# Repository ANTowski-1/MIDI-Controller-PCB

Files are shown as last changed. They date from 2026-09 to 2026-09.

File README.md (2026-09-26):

# MIDI-Controller-PCB

REV: 1 — Known problems:
    Encoder A/B pins are connected to MCP23017, which makes them unusable, so mannual connection to free ESP GPIO pins is needed,
    Leds near Mute Buttons, aren't working corrctly, as they light up very dim becouse of capabilites of MCP23017 (digital representation is working on screen),
    Some of silkscreen markings are not correct (Pin description for display header)
    
Before building using 1st revision think it through, but if you are intrested in 2nd revision, it will propably be done in the end of the year, based on intrest, so create an issue or write to me directly to let me know about your intrest!

This Repo contains KiCad projects of MIDI-Controller PCB.
Whole documentation can be found in separate repo: ANTowski-1/MIDI-Controller.
(As of end of September 2026, documentations is not made as for code still being developed)

This is an Hobbyst-made project, that isn't connected with MIDI Association in any way, apart from utilising the MIDI 2.0 standard.

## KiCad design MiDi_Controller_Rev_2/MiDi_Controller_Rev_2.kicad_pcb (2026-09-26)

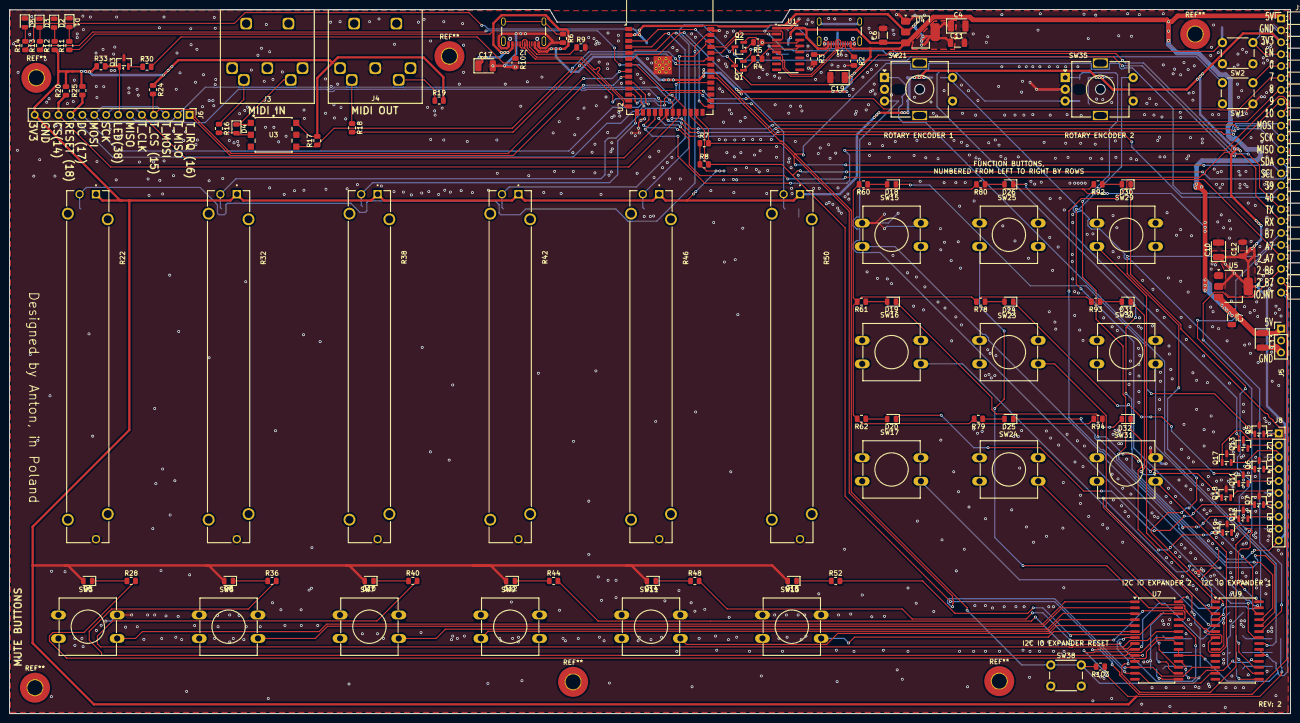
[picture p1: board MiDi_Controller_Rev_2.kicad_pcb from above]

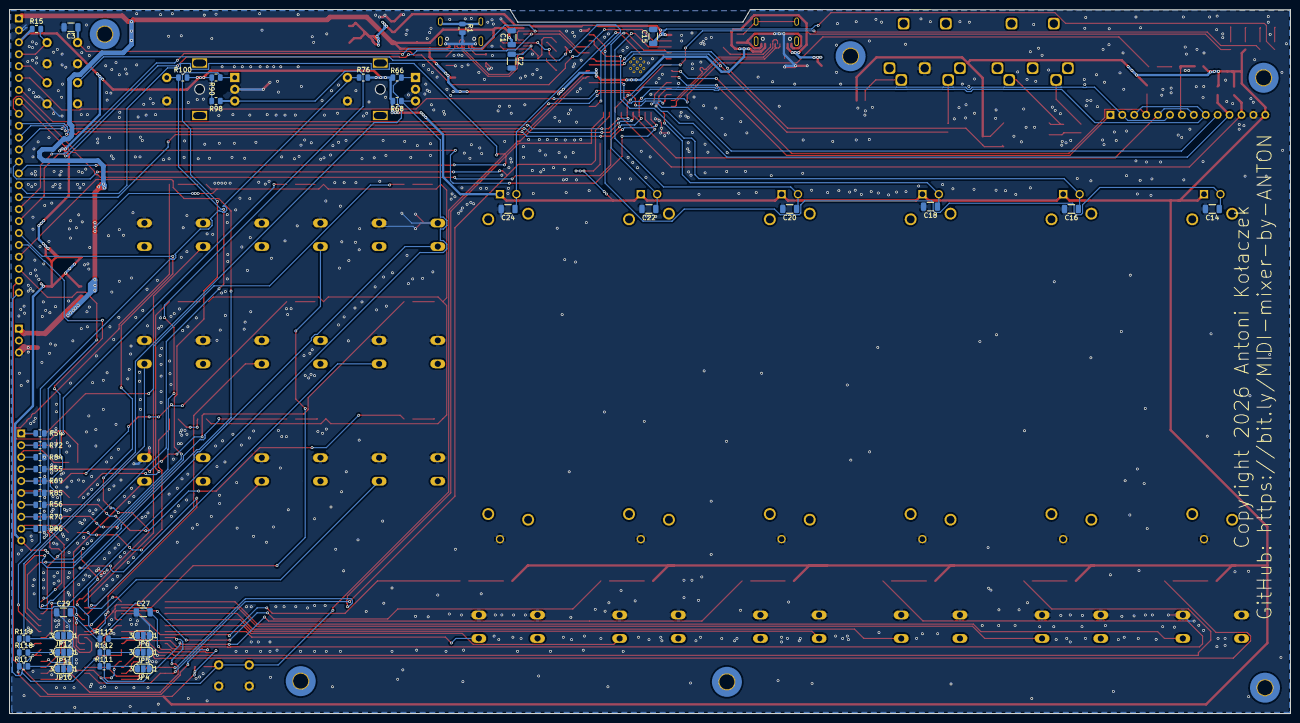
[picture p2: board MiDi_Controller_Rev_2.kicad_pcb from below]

Board: 2 copper layers, 272.9 x 150.0 mm, 161 parts (41 on the bottom side), 138 nets.

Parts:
C1, C2, C14, C15, C16, C18, C20, C22, C24: 100nF; C_1206_3216Metric
C3: 1u; C_1206_3216Metric
C4, C10: C_Polarized; CP_EIA-3528-21_Kemet-B
C6, C7, C11, C12, C27, C29: 100n; C_1206_3216Metric
C13, C17, C19: 10µ C_Polarized; CP_EIA-3528-21_Kemet-B
D1, D18, D19, D20, D24, D25, D26, D30, D31, D32: BLUE; LED_0805_2012Metric
D2, D5: GREEN; LED_0805_2012Metric
D3, D6, D8, D10, D12, D14, D16: RED; LED_0805_2012Metric
D4: D; D_0805_2012Metric
J1, J2: USB_C_Receptacle_USB2.0_16P; USB_C_Receptacle_GCT_USB4105-xx-A_16P_TopMnt_Horizontal
J3, J4: DIN-5; DIN-5-lumberg-0105
J5: Conn_01x03_Pin; PinHeader_1x03_P2.54mm_Vertical
J6: Display; PinHeader_1x14_P2.54mm_Vertical
J8: KEYPAD_LEDS; PinSocket_1x10_P2.54mm_Vertical
J10: Conn_01x24_Pin; PinHeader_1x24_P2.54mm_Horizontal
JP4, JP5, JP6, JP10, JP11, JP12: Jumper_3_Bridged12; SolderJumper-3_P1.3mm_Open_RoundedPad1.0x1.5mm_NumberLabels
Q1, Q2: BC817; SOT-23
Q3, Q5, Q6, Q7, Q11, Q12, Q13, Q17, Q18, Q19: NMOS; SOT-23
R1, R6: 1M; R_0805_2012Metric
R2, R3, R9, R10: 5k1; R_0805_2012Metric
R4, R5, R20, R24, R25, R30, R33, R54, R55, R56, R69, R70, R72, R84, R85, R86: 10K; R_0805_2012Metric
R7, R8: 4k7; R_0805_2012Metric
R11, R60, R61, R62, R78, R79, R80, R92, R93, R94: 110R; R_0805_2012Metric
R12, R14: 47R; R_0805_2012Metric
R13, R28, R36, R40, R44, R48, R52: 82R; R_0805_2012Metric
R15: 5.1K; R_0805_2012Metric
R16, R18: 220R; R_0805_2012Metric
R17: 680R; R_0805_2012Metric
R19: 33R; R_0805_2012Metric
R22, R32, R38, R42, R46, R50: PTA6043-2015DPB103; TRIM_PTA6043-2015DPB103
R66, R68, R76, R90, R98, R100, R103, R111, R112, R113, R117, R118, R119: 10k; R_0805_2012Metric
SW1, SW2: TS-1088-AR02016; SW_PUSH_6mm_H5mm
SW3, SW5, SW7, SW9, SW11, SW13, SW15, SW16, SW17, SW23, SW24, SW25, SW29, SW30, SW31: SW_Push; SW_PUSH-12mm
SW21, SW35: RotaryEncoder_Switch; RotaryEncoder_Alps_EC11E-Switch_Vertical_H20mm_MountingHoles
SW38: SW_Push; SW_PUSH_6mm_H4.3mm
U1: CH340C; SOIC-16_3.9x9.9mm_P1.27mm
U2: ESP32-S3-WROOM-1
U3: H11L1; H11L1STA_EVE
U4, U5: AMS1117-3.3; SOT-223-3_TabPin2
U7, U9: MCP23017x-x-SO; SOIC-28W_7.5x17.9mm_P1.27mm

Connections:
2_GPA0: R28.2, U7.21 (GPA0)
2_GPA1: R36.2, U7.22 (GPA1)
2_GPA2: R40.2, U7.23 (GPA2)
2_GPA3: R44.2, U7.24 (GPA3)
2_GPA4: R48.2, U7.25 (GPA4)
2_GPA5: R52.2, U7.26 (GPA5)
2_GPA6: SW25.2, U7.27 (GPA6)
2_GPA7: J10.21, U7.28 (GPA7)
2_GPB0: SW3.2, U7.1 (GPB0)
2_GPB1: SW5.2, U7.2 (GPB1)
2_GPB2: SW7.2, U7.3 (GPB2)
2_GPB3: SW9.2, U7.4 (GPB3)
2_GPB4: SW11.2, U7.5 (GPB4)
2_GPB5: SW13.2, U7.6 (GPB5)
2_GPB6: J10.22, U7.7 (GPB6)
2_GPB7: J10.23, U7.8 (GPB7)
+3V3: C10.1, C12.1, C27.2, C29.2, D6.2 (A), D8.2 (A), D10.2 (A), D12.2 (A), D14.2 (A), D16.2 (A), J6.14, J8.10, J10.3, R7.1, R8.1, R12.1, R15.1, R17.2, R19.2, R20.2, R22.1, R24.1, R25.2, R32.1, R33.1, R38.1, R42.1, R46.1, R50.1, R66.2, R68.2, R76.2, R90.2, R98.2, R100.2, R103.1, R111.1, R112.1, R113.1, R117.1, R118.1, R119.1, U3.6, U5.2 (VO), U7.9 (V_{DD}), U9.9 (V_{DD})
+5V: C1.1, C6.1, C7.1, C13.1, C17.1, C19.1, J1.A4 (VBUS), J1.A9 (VBUS), J1.B4 (VBUS), J1.B9 (VBUS), J2.A4 (VBUS), J2.A9 (VBUS), J2.B4 (VBUS), J2.B9 (VBUS), J5.1, J10.1, R11.1, R60.2, R61.2, R62.2, R78.2, R79.2, R80.2, R92.2, R93.2, R94.2, U1.16 (VCC), U4.3 (VI), U5.3 (VI)
A0: JP10.2 (C), U9.15 (A0)
A0_2: JP4.2 (C), U7.15 (A0)
A1: JP11.2 (C), U9.16 (A1)
A1_2: JP5.2 (C), U7.16 (A1)
A2: JP12.2 (C), U9.17 (A2)
A2_2: JP6.2 (C), U7.17 (A2)
D+: J2.A6 (D+), J2.B6 (D+), U2.14 (USB_D+)
D-: J2.A7 (D-), J2.B7 (D-), U2.13 (USB_D-)
DS+: J1.A6 (D+), J1.B6 (D+), U1.5 (UD+)
DS-: J1.A7 (D-), J1.B7 (D-), U1.6 (UD-)
EN: C3.1, J10.4, Q1.3 (C), R15.2, SW2.2, U2.3 (EN)
GND: C1.2, C2.2, C3.2, C4.2, C6.2, C7.2, C10.2, C11.2, C12.2, C13.2, C14.2, C15.2, C16.2, C17.2, C18.2, C19.2, C20.2, C22.2, C24.2, C27.1, C29.1, D1.1 (K), D2.1 (K), D3.1 (K), D5.1 (K), J1.A1 (GND), J1.A12 (GND), J1.B1 (GND), J1.B12 (GND), J2.A1 (GND), J2.A12 (GND), J2.B1 (GND), J2.B12 (GND), J4.2, J5.3, J6.13, J10.2, JP4.1 (A), JP5.1 (A), JP6.1 (A), JP10.1 (A), JP11.1 (A), JP12.1 (A), Q3.3 (S), Q5.3 (S), Q6.3 (S), Q7.3 (S), Q11.3 (S), Q12.3 (S), Q13.3 (S), Q17.3 (S), Q18.3 (S), Q19.3 (S), R1.2, R2.2, R3.2, R6.2, R9.2, R10.2, R22.3, R32.3, R38.3, R42.3, R46.3, R50.3, R54.1, R55.1, R56.1, R69.1, R70.1, R72.1, R84.1, R85.1, R86.1, SW1.1, SW2.1, SW3.1, SW5.1, SW7.1, SW9.1, SW11.1, SW13.1, SW15.1, SW16.1, SW17.1, SW21.C, SW21.S1, SW23.1, SW24.1, SW25.1, SW29.1, SW30.1, SW31.1, SW35.C, SW35.S1, SW38.2, U1.1 (GND), U2.1 (GND), U2.40 (GND), U2.41 (GND), U3.5, U4.1 (GND), U5.1 (GND), U7.10 (V_{SS}), U9.10 (V_{SS})
GPA0: R66.1, SW21.A, U9.21 (GPA0)
GPA1: R68.1, SW21.B, U9.22 (GPA1)
GPA2: R76.1, SW21.S2, U9.23 (GPA2)
GPA3: R90.1, SW35.A, U9.24 (GPA3)
GPA4: R98.1, SW35.B, U9.25 (GPA4)
GPA5: R100.1, SW35.S2, U9.26 (GPA5)
GPA6: SW15.2, U9.27 (GPA6)
GPA7: J10.20, U9.28 (GPA7)
GPB0: SW29.2, U9.1 (GPB0)
GPB1: SW16.2, U9.2 (GPB1)
GPB2: SW23.2, U9.3 (GPB2)
GPB3: SW30.2, U9.4 (GPB3)
GPB4: SW17.2, U9.5 (GPB4)
GPB5: SW24.2, U9.6 (GPB5)
GPB6: SW31.2, U9.7 (GPB6)
GPB7: J10.19, U9.8 (GPB7)
GPIO0: J10.5, Q2.3 (C), SW1.2, U2.27 (IO0)
GPIO1: C14.1, R22.2, U2.39 (IO1)
GPIO2: C16.1, R32.2, U2.38 (IO2)
GPIO3: C18.1, R38.2, U2.15 (IO3)
GPIO4: C20.1, R42.2, U2.4 (IO4)
GPIO5: C22.1, R46.2, U2.5 (IO5)
GPIO6: C24.1, R50.2, U2.6 (IO6)
GPIO7: J10.6, U2.7 (IO7)
GPIO8: J10.7, U2.12 (IO8)
GPIO9: J10.8, U2.17 (IO9)
GPIO10: J10.9, U2.18 (IO10)
GPIO11: J6.3, J6.9, J10.10, U2.19 (IO11)
GPIO12: J6.5, J6.8, J10.11, U2.20 (IO12)
GPIO13: J6.2, J6.6, J10.12, U2.21 (IO13)
GPIO14: J6.12, R20.1, U2.22 (IO14)
GPIO15: J6.4, R24.2, U2.8 (IO15)
GPIO16: J6.1, U2.9 (IO16)
GPIO17: J6.10, U2.10 (IO17)
GPIO18: J6.11, R25.1, U2.11 (IO18)
GPIO21: R13.1, U2.23 (IO21)
GPIO38: R30.2, U2.31 (IO38)
GPIO39: J10.15, R103.2, SW38.1, U2.32 (IO39), U7.18 (~RESET), U9.18 (~RESET)
GPIO40: J10.16, U2.33 (IO40)
GPIO41: R18.2, U2.34 (IO41)
GPIO42: R17.1, U2.35 (IO42), U3.4
INTA: J10.24, U7.19 (INTB), U7.20 (INTA), U9.19 (INTB), U9.20 (INTA)
unnamed: D1.2 (A), R11.2
unnamed: D2.2 (A), R12.2
unnamed: D3.2 (A), R13.2
unnamed: D4.2 (A), R16.2, U3.2
unnamed: D4.1 (K), J3.5, U3.1
unnamed: D5.2 (A), R14.2
unnamed: D6.1 (K), R28.1
unnamed: D8.1 (K), R36.1
unnamed: D10.1 (K), R40.1
unnamed: D12.1 (K), R44.1
unnamed: D14.1 (K), R48.1
unnamed: D16.1 (K), R52.1
unnamed: D18.2 (A), R60.1
unnamed: D18.1 (K), Q5.1 (D)
unnamed: D19.2 (A), R61.1
unnamed: D19.1 (K), Q6.1 (D)
unnamed: D20.2 (A), R62.1
unnamed: D20.1 (K), Q7.1 (D)
unnamed: D24.2 (A), R78.1
unnamed: D24.1 (K), Q11.1 (D)
unnamed: D25.2 (A), R79.1
unnamed: D25.1 (K), Q12.1 (D)
unnamed: D26.2 (A), R80.1
unnamed: D26.1 (K), Q13.1 (D)
unnamed: D30.2 (A), R92.1
unnamed: D30.1 (K), Q17.1 (D)
unnamed: D31.2 (A), R93.1
unnamed: D31.1 (K), Q18.1 (D)
unnamed: D32.2 (A), R94.1
unnamed: D32.1 (K), Q19.1 (D)
unnamed: J1.A5 (CC1), R2.1
unnamed: J1.B5 (CC2), R3.1
unnamed: J1.SH (SHIELD), R1.1
unnamed: J2.A5 (CC1), R9.1
unnamed: J2.B5 (CC2), R10.1
unnamed: J2.SH (SHIELD), R6.1
unnamed: J3.4, R16.1
unnamed: J4.4, R18.1
unnamed: J4.5, R19.1
unnamed: J6.7, Q3.1 (D), R33.2
unnamed: JP4.3 (B), R111.2
unnamed: JP5.3 (B), R112.2
unnamed: JP6.3 (B), R113.2
unnamed: JP10.3 (B), R117.2
unnamed: JP11.3 (B), R118.2
unnamed: JP12.3 (B), R119.2
unnamed: Q1.1 (B), R4.2
unnamed: Q1.2 (E), R5.1, U1.14 (~RTS)
unnamed: Q2.1 (B), R5.2
unnamed: Q2.2 (E), R4.1, U1.13 (~DTR)
unnamed: Q3.2 (G), R30.1
unnamed: C2.1, U1.4 (V3)
RX0: J10.18, U1.2 (TXD), U2.36 (RXD0)
SCL: J10.14, R7.2, U2.25 (IO48), U7.12 (SCK), U9.12 (SCK)
SDA: J10.13, R8.2, U2.24 (IO47), U7.13 (SDA), U9.13 (SDA)
SL1: J8.1, Q5.2 (G), R54.2
SL2: J8.2, Q13.2 (G), R72.2
SL3: J8.3, Q17.2 (G), R84.2
SL4: J8.4, Q6.2 (G), R55.2
SL5: J8.5, Q11.2 (G), R69.2
SL6: J8.6, Q18.2 (G), R85.2
SL7: J8.7, Q7.2 (G), R56.2
SL8: J8.8, Q12.2 (G), R70.2
SL9: J8.9, Q19.2 (G), R86.2
TX0: J10.17, U1.3 (RXD), U2.37 (TXD0)
VCC: C4.1, C11.1, C15.1, R14.1, U2.2 (3V3), U4.2 (VO)

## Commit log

2026-05-17 Adding PCB files
2026-05-17 Revert "Adding PCB files"
    This reverts commit 5f1f5a5b989860db797b21627ae796cebe1ef32a.
2026-05-18 Restore Both PCB revisions
    [IO_expanders.kicad_sch, MiDi_Controller_Rev_1.kicad_pcb, MiDi_Controller_Rev_1.kicad_sch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]
2026-09-26 Changed README.md so rev 1 lists actual problems, not a wide expression.
    [MiDi_Controller_Rev_1-B_Cu.gbl, MiDi_Controller_Rev_1-B_Mask.gbs, MiDi_Controller_Rev_1-B_Paste.gbp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]

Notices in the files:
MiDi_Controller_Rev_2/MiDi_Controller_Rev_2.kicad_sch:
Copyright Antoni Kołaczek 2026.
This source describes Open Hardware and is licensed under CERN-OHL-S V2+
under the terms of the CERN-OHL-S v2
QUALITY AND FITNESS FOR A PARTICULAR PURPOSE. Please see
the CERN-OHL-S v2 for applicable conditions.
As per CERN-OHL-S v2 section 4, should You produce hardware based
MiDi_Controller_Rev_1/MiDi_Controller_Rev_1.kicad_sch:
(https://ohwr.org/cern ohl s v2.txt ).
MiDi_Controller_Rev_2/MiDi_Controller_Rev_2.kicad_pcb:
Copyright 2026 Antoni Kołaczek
